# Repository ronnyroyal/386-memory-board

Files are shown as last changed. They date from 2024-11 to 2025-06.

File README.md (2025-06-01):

# 386 memory board by ronnyroy

This is an attempt to reproduce and improve the 32 bit memory expansion cards of the Intel 301 386 mainboard https://theretroweb.com/motherboards/s/intel-301-system-board-pba-451213-xxx based off my original 2MB card.  
Instead of 41256 DIP DRAM chips it uses 30pin SIMM modules, all SMD parts and can also be adapted to 8MB.  

Big thanks to i440bx who was working on reverse engineering his own card independently and helped greatly by finding the user manual for the board and an image of the 8MB card on https://www.vaxbarn.com/index.php?option=com_content&view=article&id=749.

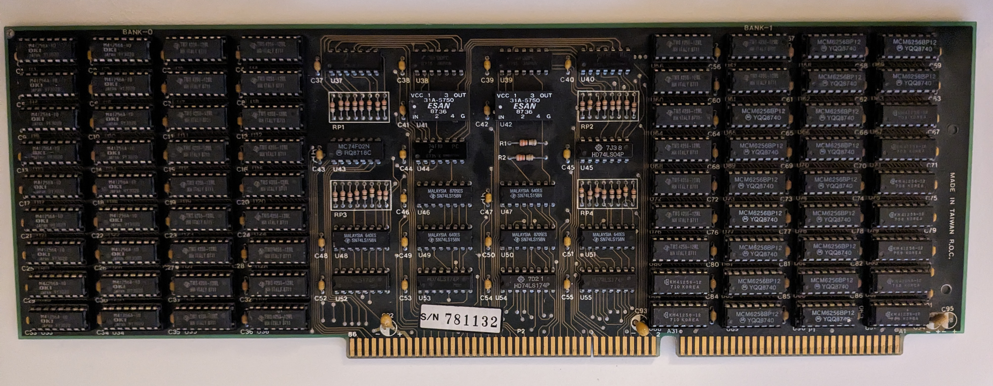
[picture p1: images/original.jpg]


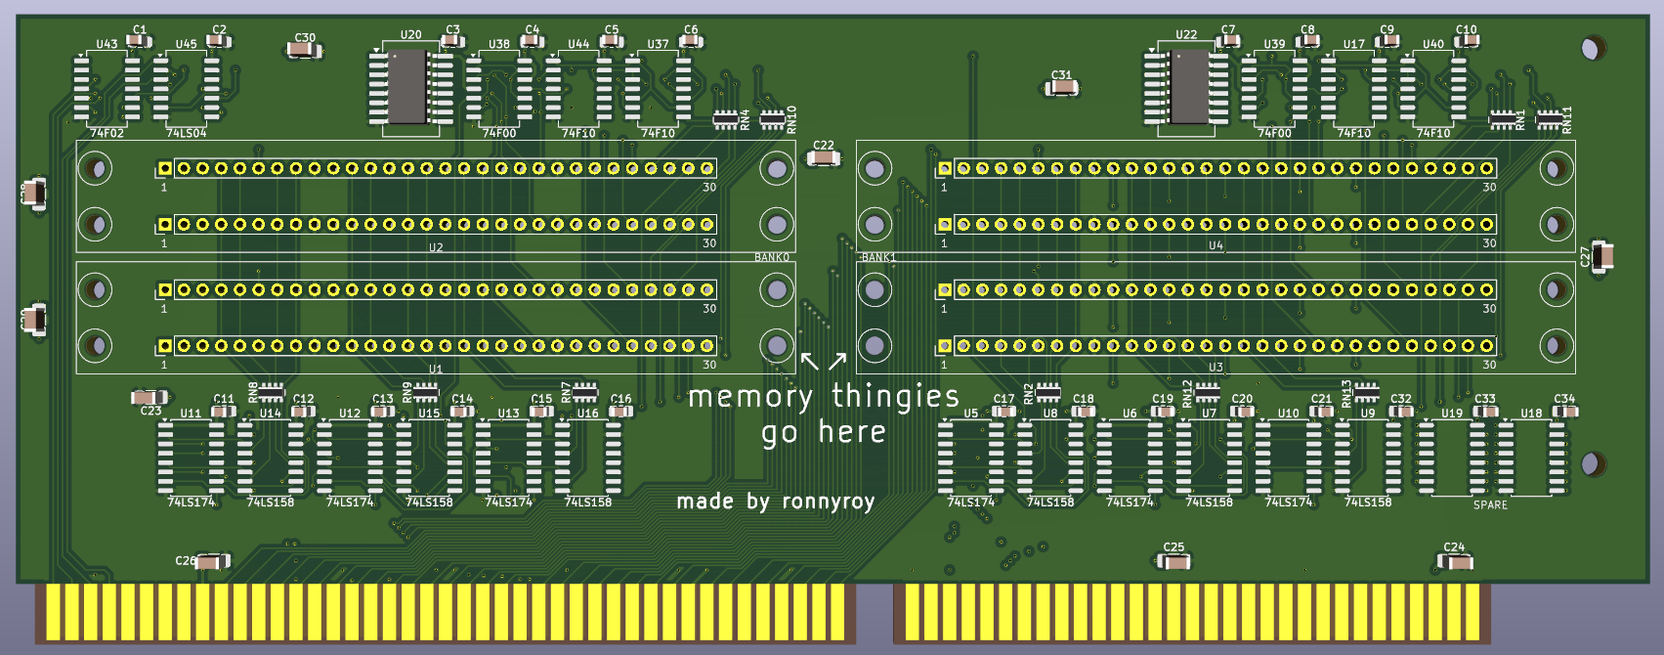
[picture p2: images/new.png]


# Initial Revision
The initial PCB revision has been tested and confirmed working.  
It was designed to test my clone of the 2MB card and for modding it to 8MB.



### Modding to 8MB
- CPUA21(pin85) on the slot to pin 5 of U9 and U16.  
- CPUA22(pin95) on the slot to pin 4 of U10 and U13.

# Second Revision
This adds the missing traces and jumpers required for 2/8MB operation and the slot cutout i excluded from rev.1.  

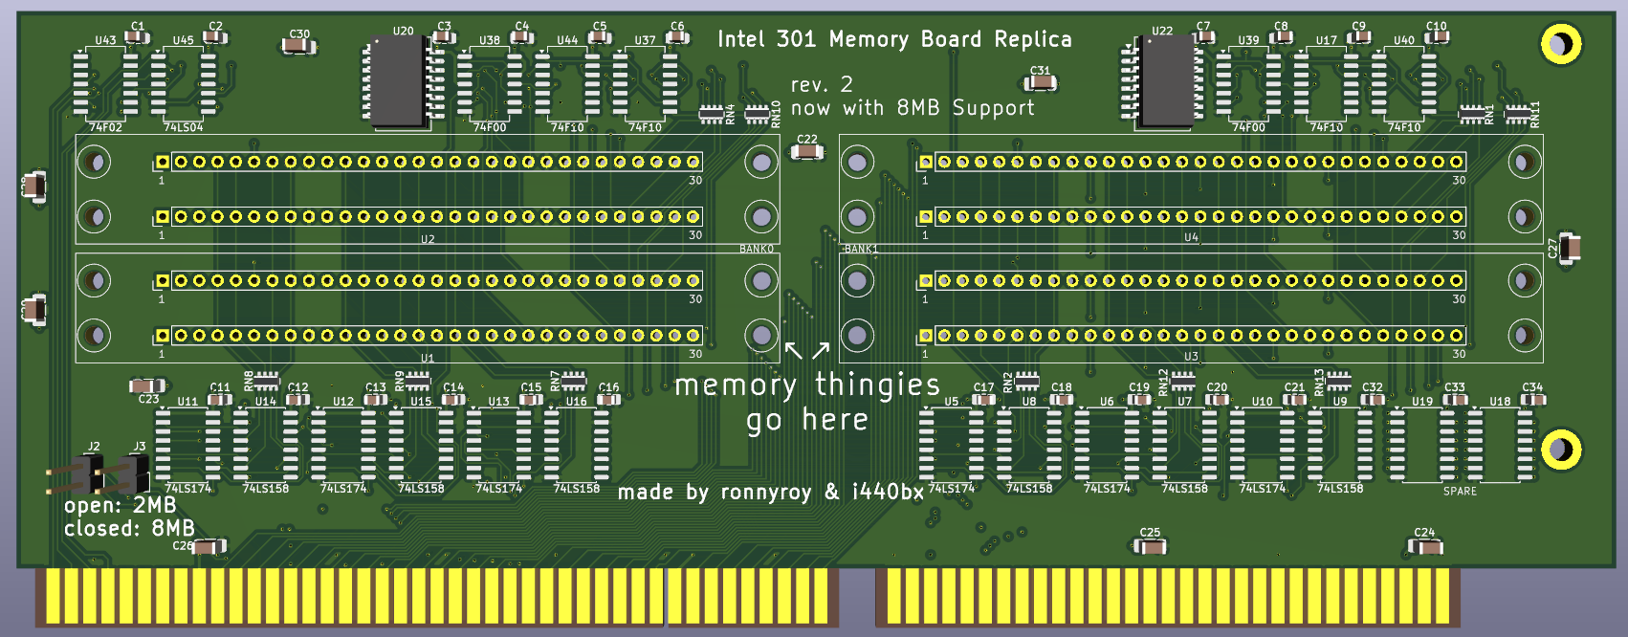
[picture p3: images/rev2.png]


# Important!
An 8MB card configured to 2MB on the mainboard will start up fine and even pass an extended CheckIt memory test but running programs that use the memory of the card crash.  
So the card needs to be configured matching to the mainboard.

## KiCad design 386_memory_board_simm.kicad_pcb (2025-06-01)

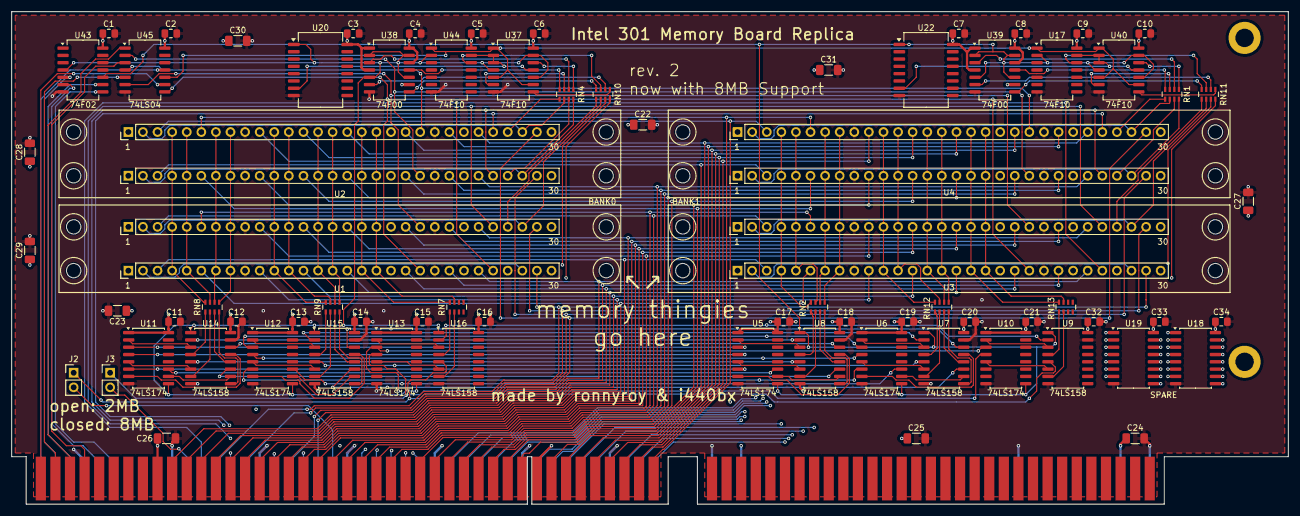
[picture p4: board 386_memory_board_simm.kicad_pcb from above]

Board: 4 copper layers, 222.2 x 85.7 mm, 77 parts (0 on the bottom side), 174 nets.

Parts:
C1, C2, C3, C4, C5, C6, C7, C8, C9, C10, C11, C12, C13, C14, C15, C16, C17, C18, C19, C20, C21, C32, C33, C34: 100nF; C_0805_2012Metric_Pad1.18x1.45mm_HandSolder
C22, C23, C24, C25, C26, C27, C28, C29, C30, C31: 10µF; C_1206_3216Metric_Pad1.33x1.80mm_HandSolder
H1, H2: MountingHole; MountingHole_3.2mm_M3_DIN965_Pad
J1: Bus_386_Memory; BUS_386_MEMORY
J2, J3: Conn_01x02_Pin; PinHeader_1x02_P2.54mm_Vertical
RN1, RN2, RN4, RN7, RN8, RN9, RN10, RN11, RN12, RN13: 33Ω; R_Array_Concave_4x0603
U1, U2, U3, U4: DOUBLE-SIMM-30
U5, U6, U10, U11, U12, U13: 74LS174; SO-16_5.3x10.2mm_P1.27mm
U7, U8, U9, U14, U15, U16: 74LS158; SO-16_5.3x10.2mm_P1.27mm
U17, U37, U40, U44: 74F10; SO-14_5.3x10.2mm_P1.27mm
U18, U19: SPARE; SO-16_5.3x10.2mm_P1.27mm
U20, U22: SOIC-16W_7.5x12.8mm_P1.27mm
U38, U39: 74F00; SO-14_5.3x10.2mm_P1.27mm
U43: 74F02; SO-14_5.3x10.2mm_P1.27mm
U45: 74LS04; SO-14_5.3x10.2mm_P1.27mm

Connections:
A0A: J1.63 (CPUA3), U8.2 (I0a), U14.2 (I0a)
A0B: J1.70 (CPUA12), U5.3 (D0), U11.3 (D0)
A0B0: RN8.8 (R1.2), U1.4A (A0A), U1.4B (A0B), U2.4A (A0A), U2.4B (A0B)
A0B1: RN2.8 (R1.2), U3.4A (A0A), U3.4B (A0B), U4.4A (A0A), U4.4B (A0B)
A1A: J1.64 (CPUA4), U8.5 (I0b), U14.5 (I0b)
A1B: J1.71 (CPUA13), U5.4 (D1), U11.4 (D1)
A1B0: RN8.7 (R2.2), U1.5A (A1A), U1.5B (A1B), U2.5A (A1A), U2.5B (A1B)
A1B1: RN2.7 (R2.2), U3.5A (A1A), U3.5B (A1B), U4.5A (A1A), U4.5B (A1B)
A2A: J1.65 (CPUA5), U8.14 (I0c), U14.14 (I0c)
A2B: J1.73 (CPUA14), U5.6 (D2), U11.6 (D2)
A2B0: RN8.6 (R3.2), U1.7A (A2A), U1.7B (A2B), U2.7A (A2A), U2.7B (A2B)
A2B1: RN2.6 (R3.2), U3.7A (A2A), U3.7B (A2B), U4.7A (A2A), U4.7B (A2B)
A3A: J1.67 (CPUA6), U8.11 (I0d), U14.11 (I0d)
A3B: J1.74 (CPUA15), U5.11 (D3), U11.11 (D3)
A3B0: RN8.5 (R4.2), U1.8A (A3A), U1.8B (A3B), U2.8A (A3A), U2.8B (A3B)
A3B1: RN2.5 (R4.2), U3.8A (A3A), U3.8B (A3B), U4.8A (A3A), U4.8B (A3B)
A4A: J1.68 (CPUA7), U7.2 (I0a), U15.2 (I0a)
A4B: J1.75 (CPUA16), U6.3 (D0), U12.3 (D0)
A4B0: RN9.8 (R1.2), U1.11A (A4A), U1.11B (A4B), U2.11A (A4A), U2.11B (A4B)
A4B1: RN12.8 (R1.2), U3.11A (A4A), U3.11B (A4B), U4.11A (A4A), U4.11B (A4B)
A5A: J1.81 (RA8), U7.5 (I0b), U15.5 (I0b)
A5B: J1.76 (CPUA17), U6.4 (D1), U12.4 (D1)
A5B0: RN9.7 (R2.2), U1.12A (A5A), U1.12B (A5B), U2.12A (A5A), U2.12B (A5B)
A5B1: RN12.7 (R2.2), U3.12A (A5A), U3.12B (A5B), U4.12A (A5A), U4.12B (A5B)
A6A: J1.82 (RA9), U7.14 (I0c), U15.14 (I0c)
A6B: J1.77 (CPUA18), U6.6 (D2), U12.6 (D2)
A6B0: RN9.6 (R3.2), U1.14A (A6A), U1.14B (A6B), U2.14A (A6A), U2.14B (A6B)
A6B1: RN12.6 (R3.2), U3.14A (A6A), U3.14B (A6B), U4.14A (A6A), U4.14B (A6B)
A7A: J1.83 (RA10), U7.11 (I0d), U15.11 (I0d)
A7B: J1.79 (CPUA19), U6.11 (D3), U12.11 (D3)
A7B0: RN9.5 (R4.2), U1.15A (A7A), U1.15B (A7B), U2.15A (A7A), U2.15B (A7B)
A7B1: RN12.5 (R4.2), U3.15A (A7A), U3.15B (A7B), U4.15A (A7A), U4.15B (A7B)
A8A: J1.69 (RA11), U9.2 (I0a), U16.2 (I0a)
A8B: J1.80 (CPUA20), U10.3 (D0), U13.3 (D0)
A8B0: RN7.8 (R1.2), U1.17A (A8A), U1.17B (A8B), U2.17A (A8A), U2.17B (A8B)
A8B1: RN13.8 (R1.2), U3.17A (A8A), U3.17B (A8B), U4.17A (A8A), U4.17B (A8B)
A9A: J2.1, U9.5 (I0b), U16.5 (I0b)
A9B: J3.1, U10.4 (D1), U13.4 (D1)
A9B0: RN7.7 (R2.2), U1.18A (A9A), U1.18B (A9B), U2.18A (A9A), U2.18B (A9B)
A9B1: RN13.7 (R2.2), U3.18A (A9A), U3.18B (A9B), U4.18A (A9A), U4.18B (A9B)
CPUA21: J1.85 (CPUA21), J2.2
CPUA22: J1.95 (CPUA22), J3.2
D0R0: J1.132 (EXPD24), U1.3A (D0A), U3.3A (D0A)
D0R1: J1.124 (EXPD16), U1.3B (D0B), U3.3B (D0B)
D0R2: J1.115 (EXPD8), U2.3A (D0A), U4.3A (D0A)
D0R3: J1.106 (EXPD0), U2.3B (D0B), U4.3B (D0B)
D1R0: J1.133 (EXPD25), U1.6A (D1A), U3.6A (D1A)
D1R1: J1.125 (EXPD17), U1.6B (D1B), U3.6B (D1B)
D1R2: J1.116 (EXPD9), U2.6A (D1A), U4.6A (D1A)
D1R3: J1.107 (EXPD1), U2.6B (D1B), U4.6B (D1B)
D2R0: J1.134 (EXPD26), U1.10A (D2A), U3.10A (D2A)
D2R1: J1.126 (EXPD18), U1.10B (D2B), U3.10B (D2B)
D2R2: J1.117 (EXPD10), U2.10A (D2A), U4.10A (D2A)
D2R3: J1.108 (EXPD2), U2.10B (D2B), U4.10B (D2B)
D3R0: J1.135 (EXPD27), U1.13A (D3A), U3.13A (D3A)
D3R1: J1.127 (EXPD19), U1.13B (D3B), U3.13B (D3B)
D3R2: J1.118 (EXPD11), U2.13A (D3A), U4.13A (D3A)
D3R3: J1.109 (EXPD3), U2.13B (D3B), U4.13B (D3B)
D4R0: J1.136 (EXPD28), U1.16A (D4A), U3.16A (D4A)
D4R1: J1.128 (EXPD20), U1.16B (D4B), U3.16B (D4B)
D4R2: J1.119 (EXPD12), U2.16A (D4A), U4.16A (D4A)
D4R3: J1.110 (EXPD4), U2.16B (D4B), U4.16B (D4B)
D5R0: J1.137 (EXPD29), U1.20A (D5A), U3.20A (D5A)
D5R1: J1.129 (EXPD21), U1.20B (D5B), U3.20B (D5B)
D5R2: J1.120 (EXPD13), U2.20A (D5A), U4.20A (D5A)
D5R3: J1.111 (EXPD5), U2.20B (D5B), U4.20B (D5B)
D6R0: J1.138 (EXPD30), U1.23A (D6A), U3.23A (D6A)
D6R1: J1.130 (EXPD22), U1.23B (D6B), U3.23B (D6B)
D6R2: J1.121 (EXPD14), U2.23A (D6A), U4.23A (D6A)
D6R3: J1.112 (EXPD6), U2.23B (D6B), U4.23B (D6B)
D7R0: J1.139 (EXPD31), U1.25A (D7A), U3.25A (D7A)
D7R1: J1.131 (EXPD23), U1.25B (D7B), U3.25B (D7B)
D7R2: J1.122 (EXPD15), U2.25A (D7A), U4.25A (D7A)
D7R3: J1.113 (EXPD7), U2.25B (D7B), U4.25B (D7B)
DIN8R0: J1.93 (PI24_31), U1.29A (P-INA), U3.29A (P-INA)
DIN8R1: J1.91 (PI16_23), U1.29B (P-INB), U3.29B (P-INB)
DIN8R2: J1.88 (PI8_15), U2.29A (P-INA), U4.29A (P-INA)
DIN8R3: J1.86 (PI0_7), U2.29B (P-INB), U4.29B (P-INB)
DOUT8R0: J1.94 (P024_31), U1.26A (P-OUTA), U3.26A (P-OUTA)
DOUT8R1: J1.92 (PO16_23), U1.26B (P-OUTB), U3.26B (P-OUTB)
DOUT8R2: J1.89 (PO8_15), U2.26A (P-OUTA), U4.26A (P-OUTA)
DOUT8R3: J1.87 (PO0_7), U2.26B (P-OUTB), U4.26B (P-OUTB)
MEMREF: J1.105 (MEMREF), U45.11
unnamed: RN1.1 (R1.1), U40.12
unnamed: RN1.2 (R2.1), U39.3
unnamed: RN1.3 (R3.1), U40.6
unnamed: RN1.4 (R4.1), U39.11
unnamed: RN2.1 (R1.1), U8.4 (Za)
unnamed: RN2.2 (R2.1), U8.7 (Zb)
unnamed: RN2.3 (R3.1), U8.12 (Zc)
unnamed: RN2.4 (R4.1), U8.9 (Zd)
unnamed: RN4.1 (R1.1), U37.12
unnamed: RN4.2 (R2.1), U38.3
unnamed: RN4.3 (R3.1), U37.6
unnamed: RN4.4 (R4.1), U38.11
unnamed: RN7.1 (R1.1), U16.4 (Za)
unnamed: RN7.2 (R2.1), U16.7 (Zb)
unnamed: RN8.1 (R1.1), U14.4 (Za)
unnamed: RN8.2 (R2.1), U14.7 (Zb)
unnamed: RN8.3 (R3.1), U14.12 (Zc)
unnamed: RN8.4 (R4.1), U14.9 (Zd)
unnamed: RN9.1 (R1.1), U15.4 (Za)
unnamed: RN9.2 (R2.1), U15.7 (Zb)
unnamed: RN9.3 (R3.1), U15.12 (Zc)
unnamed: RN9.4 (R4.1), U15.9 (Zd)
unnamed: RN10.1 (R1.1), U37.8
unnamed: RN10.2 (R2.1), U38.6
unnamed: RN10.3 (R3.1), U44.12
unnamed: RN10.4 (R4.1), U38.8
unnamed: RN11.1 (R1.1), U40.8
unnamed: RN11.2 (R2.1), U39.6
unnamed: RN11.3 (R3.1), U17.12
unnamed: RN11.4 (R4.1), U39.8
unnamed: RN12.1 (R1.1), U7.4 (Za)
unnamed: RN12.2 (R2.1), U7.7 (Zb)
unnamed: RN12.3 (R3.1), U7.12 (Zc)
unnamed: RN12.4 (R4.1), U7.9 (Zd)
unnamed: RN13.1 (R1.1), U9.4 (Za)
unnamed: RN13.2 (R2.1), U9.7 (Zb)
unnamed: U5.2 (Q0), U8.3 (I1a)
unnamed: U5.5 (Q1), U8.6 (I1b)
unnamed: U5.7 (Q2), U8.13 (I1c)
unnamed: U5.10 (Q3), U8.10 (I1d)
unnamed: U6.2 (Q0), U7.3 (I1a)
unnamed: U6.5 (Q1), U7.6 (I1b)
unnamed: U6.7 (Q2), U7.13 (I1c)
unnamed: U6.10 (Q3), U7.10 (I1d)
unnamed: U9.3 (I1a), U10.2 (Q0)
unnamed: U9.6 (I1b), U10.5 (Q1)
unnamed: U11.2 (Q0), U14.3 (I1a)
unnamed: U11.5 (Q1), U14.6 (I1b)
unnamed: U11.7 (Q2), U14.13 (I1c)
unnamed: U11.10 (Q3), U14.10 (I1d)
unnamed: U12.2 (Q0), U15.3 (I1a)
unnamed: U12.5 (Q1), U15.6 (I1b)
unnamed: U12.7 (Q2), U15.13 (I1c)
unnamed: U12.10 (Q3), U15.10 (I1d)
unnamed: U13.2 (Q0), U16.3 (I1a)
unnamed: U13.5 (Q1), U16.6 (I1b)
unnamed: U20.7 (TAP8), U37.2, U37.3, U37.11, U44.13
unnamed: U17.13, U22.7 (TAP8), U40.2, U40.3, U40.11
RMSEL0: J1.103 (RMSEL0), U43.9
RMSEL1: J1.104 (RMSEL1), U43.5
SLEB0: J1.100 (SLEB0), U43.8
SLEB1: J1.101 (SLEB1), U43.6
UNKN5: U11.9 (Cp), U12.9 (Cp), U13.9 (Cp), U14.1 (S), U15.1 (S), U16.1 (S), U20.1 (IN), U37.4, U37.10, U37.13, U38.2, U38.5, U38.10, U38.13, U43.4, U44.2
UNKN6: U5.9 (Cp), U6.9 (Cp), U7.1 (S), U8.1 (S), U9.1 (S), U10.9 (Cp), U17.2, U22.1 (IN), U39.2, U39.5, U39.10, U39.13, U40.4, U40.10, U40.13, U43.10
VCC: C1.1, C2.1, C3.1, C4.1, C5.1, C6.1, C7.1, C8.1, C9.1, C10.1, C11.1, C12.1, C13.1, C14.1, C15.1, C16.1, C17.1, C18.1, C19.1, C20.1, C21.1, C22.1, C23.1, C24.1, C25.1, C26.1, C27.1, C28.1, C29.1, C30.1, C31.1, C32.1, C33.1, C34.1, J1.3 (+5V), J1.29 (+5V), J1.78 (+5V), J1.114 (+5V), J1.140 (+5V), U1.1A (VCCA), U1.1B (VCCB), U1.30A (VCCA), U1.30B (VCCB), U2.1A (VCCA), U2.1B (VCCB), U2.30A (VCCA), U2.30B (VCCB), U3.1A (VCCA), U3.1B (VCCB), U3.30A (VCCA), U3.30B (VCCB), U4.1A (VCCA), U4.1B (VCCB), U4.30A (VCCA), U4.30B (VCCB), U5.1 (~Mr), U5.16 (VCC), U6.1 (~Mr), U6.16 (VCC), U7.16 (VCC), U8.16 (VCC), U9.16 (VCC), U10.1 (~Mr), U10.16 (VCC), U11.1 (~Mr), U11.16 (VCC), U12.1 (~Mr), U12.16 (VCC), U13.1 (~Mr), U13.16 (VCC), U14.16 (VCC), U15.16 (VCC), U16.16 (VCC), U17.14 (VCC), U18.16 (VCC), U19.16 (VCC), U20.16 (VCC), U22.16 (VCC), U37.14 (VCC), U38.1, U38.4, U38.9, U38.12, U38.14 (VCC), U39.1, U39.4, U39.9, U39.12, U39.14 (VCC), U40.14 (VCC), U43.14 (VCC), U44.14 (VCC), U45.14 (VCC)
VSS: C1.2, C2.2, C3.2, C4.2, C5.2, C6.2, C7.2, C8.2, C9.2, C10.2, C11.2, C12.2, C13.2, C14.2, C15.2, C16.2, C17.2, C18.2, C19.2, C20.2, C21.2, C22.2, C23.2, C24.2, C25.2, C26.2, C27.2, C28.2, C29.2, C30.2, C31.2, C32.2, C33.2, C34.2, J1.1 (GND), J1.10 (GND), J1.31 (GND), J1.66 (GND), J1.72 (GND), J1.84 (GND), J1.90 (GND), J1.96 (GND), J1.102 (GND), U1.9A (GNDA), U1.9B (GNDB), U1.22A (GNDA), U1.22B (GNDB), U2.9A (GNDA), U2.9B (GNDB), U2.22A (GNDA), U2.22B (GNDB), U3.9A (GNDA), U3.9B (GNDB), U3.22A (GNDA), U3.22B (GNDB), U4.9A (GNDA), U4.9B (GNDB), U4.22A (GNDA), U4.22B (GNDB), U5.8 (GND), U6.8 (GND), U7.8 (GND), U7.15 (E), U8.8 (GND), U8.15 (E), U9.8 (GND), U9.15 (E), U10.8 (GND), U11.8 (GND), U12.8 (GND), U13.8 (GND), U14.8 (GND), U14.15 (E), U15.8 (GND), U15.15 (E), U16.8 (GND), U16.15 (E), U17.7 (GND), U18.8 (GND), U19.8 (GND), U20.8 (VSS), U22.8 (VSS), U37.7 (GND), U38.7 (GND), U39.7 (GND), U40.7 (GND), U43.7 (GND), U44.7 (GND), U45.7 (GND)
WER0: J1.148 (WE_3), U45.9
WER1: J1.147 (WE_2), U45.5
WER2: J1.146 (WE_1), U45.1
WER3: J1.145 (WE_0), U45.3
~CASB0R0: RN10.8 (R1.2), U1.2A (~CASA), U1.28A (CASPA)
~CASB0R1: RN10.6 (R3.2), U1.2B (~CASB), U1.28B (CASPB)
~CASB0R2: RN4.8 (R1.2), U2.2A (~CASA), U2.28A (CASPA)
~CASB0R3: RN4.6 (R3.2), U2.2B (~CASB), U2.28B (CASPB)
~CASB1R0: RN11.8 (R1.2), U3.2A (~CASA), U3.28A (CASPA)
~CASB1R1: RN11.6 (R3.2), U3.2B (~CASB), U3.28B (CASPB)
~CASB1R2: RN1.8 (R1.2), U4.2A (~CASA), U4.28A (CASPA)
~CASB1R3: RN1.6 (R3.2), U4.2B (~CASB), U4.28B (CASPB)
~MEMREF: U17.1, U37.1, U37.5, U37.9, U40.1, U40.5, U40.9, U44.1, U45.10
~RASB0R0: RN10.7 (R2.2), U1.27A (~RASA)
~RASB0R1: RN10.5 (R4.2), U1.27B (~RASB)
~RASB0R2: RN4.7 (R2.2), U2.27A (~RASA)
~RASB0R3: RN4.5 (R4.2), U2.27B (~RASB)
~RASB1R0: RN11.7 (R2.2), U3.27A (~RASA)
~RASB1R1: RN11.5 (R4.2), U3.27B (~RASB)
~RASB1R2: RN1.7 (R2.2), U4.27A (~RASA)
~RASB1R3: RN1.5 (R4.2), U4.27B (~RASB)
~WER0: U1.21A (~WEA), U3.21A (~WEA), U45.8
~WER1: U1.21B (~WEB), U3.21B (~WEB), U45.6
~WER2: U2.21A (~WEA), U4.21A (~WEA), U45.2
~WER3: U2.21B (~WEB), U4.21B (~WEB), U45.4

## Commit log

2024-11-03 second routing pass completed
    [386_memory_board_simm.kicad_pcb, 386_memory_board_simm.kicad_sch]
2024-11-10 fixed footprint of delay lines
    [386_memory_board_simm.kicad_pcb, 386_memory_board_simm.kicad_sch]
2024-11-20 added cosmetic silkscreen and fixed IC silkscreen
2024-11-20 added bracket mounting holes
    [386_memory_board_simm.kicad_pcb, 386_memory_board_simm.kicad_sch]
2024-11-20 fixed bracket mounting holes
    [386_memory_board_simm.kicad_pcb]
2024-11-20 new pcb image
2024-12-09 final touchups before ordering first boards
    [386_memory_board_simm.kicad_pcb]
2025-01-09 Update readme with notes on first PCB revision and assembly
2025-01-09 add finished PCB image
2025-06-01 PCB Revision 2 -implements 8MB operation -fixed the missing slot cutout on rev.1 -overhauls the slot connector based on i440bx's discoveries and design -add information to modify rev.1 Boards to 8MB
    [386_memory_board_simm.kicad_pcb, 386_memory_board_simm.kicad_sch]
2025-06-01 Add images of PCB rev.2
